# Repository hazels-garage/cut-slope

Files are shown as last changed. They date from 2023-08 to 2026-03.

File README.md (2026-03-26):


<a href="https://discord.gg/jP6hvgNN8r">
  
</a>

# Cut Slope

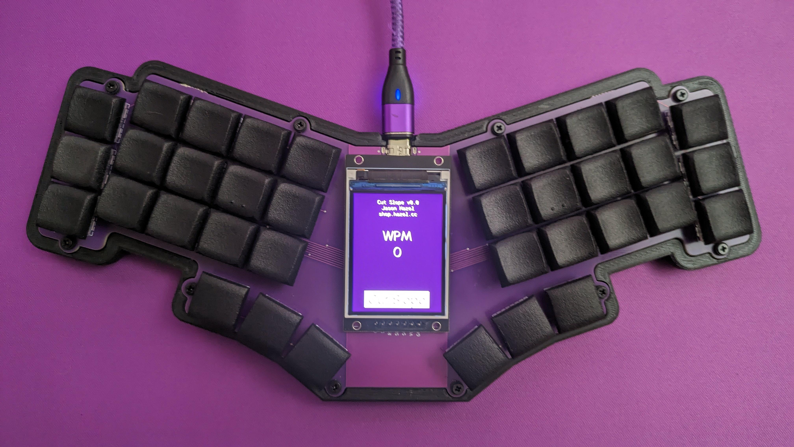
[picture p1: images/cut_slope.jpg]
Cut Slope

_I'm bad at pictures_

## Features
* Integrated RP2040.
* 36 key, choc-spaced, hotswap
* Ortho-ish with dropped/splayed pinkies and fanned thumbs
* Big ass screen support

## Build Guide
* Flash [Firmware](FIRMWARE.md)
* Test matrix with metal tweezers
* Install Hotswap Sockets
* Install Screen
* Done

## Credits
* [Hardware design with RP2040](https://datasheets.raspberrypi.com/rp2040/hardware-design-with-rp2040.pdf)
* [Sleepdealr's RP2040 Design Guide](https://github.com/Sleepdealr/RP2040-designguide)
* [eblastler's ZMK Design Guide](https://github.com/ebastler/zmk-designguide) - Got the SRV05-4 from here
* [Mabroum](https://github.com/AlaaSaadAbdo) - for screen suggestion and moral support
* [Sadek Baroudi](https://github.com/sadekbaroudi) - moral support
* [The Glitch Mob](https://www.youtube.com/watch?v=HD7XAOhkd-w) - for the name

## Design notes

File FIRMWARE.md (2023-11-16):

# Firmware
* [Personal QMK Fork](https://github.com/hazels-garage/qmk_firmware/tree/hazel/cut_slope)
* [ZMK](https://github.com/hazels-garage/zmk-cut-slope) - no wireless or screen
* [VIAL](firmware/hazel_cut_slope_vial.uf2)

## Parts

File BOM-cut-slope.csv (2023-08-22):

Comment | Designator | Footprint | LCSC
B | BOOT1,RESET1 | SW_SPST_TL3342 | C115351
1k | R3,R4 | R_0402_1005Metric | C11702
100nF | C10,C11,C12,C13,C14,C15,C16,C17,C6,C7,C8,C9 | C_0402_1005Metric | C1525
4.7n | C_Shield1 | C_0402_1005Metric | C1538
22pF | C2,C3 | C_0402_1005Metric | C1555
RP2040 | U1 | RP2040-QFN-56 | C2040
USB_C | J1 | Molex-216990_GCT-USB45xx_HRO-TYPE-C-31-M-13x | C223906
27R | R6,R7 | R_0603_1608Metric | C25190
10k | R5 | R_0402_1005Metric | C25744
5.1k | R1,R2 | R_0402_1005Metric | C25905
1M | R_Shield1 | R_0402_1005Metric | C26083
1uF | C1,C4,C5 | C_0402_1005Metric | C52923
XC6206 | U3 | SOT-23 | C5446
500mA | F1 | Fuse_1206_3216Metric | C70076
1N4148W | D1,D10,D11,D12,D13,D14,D15,D16,D17,D18,D19,D2,D20,D21,D22,D23,D24,D25,D26,D27,D28,D29,D3,D30,D31,D32,D33,D34,D35,D36,D4,D5,D6,D7,D8,D9 | D_SOD-123 | C81598
SRV05-4 | U2 | SOT-23-6-routable | C85364
12MHz | Y1 | Crystal_SMD_3225-4Pin_3.2x2.5mm | C9002
W25Q128JVS | U4 | SOIC-8_5.23x5.23mm_P1.27mm | C97521

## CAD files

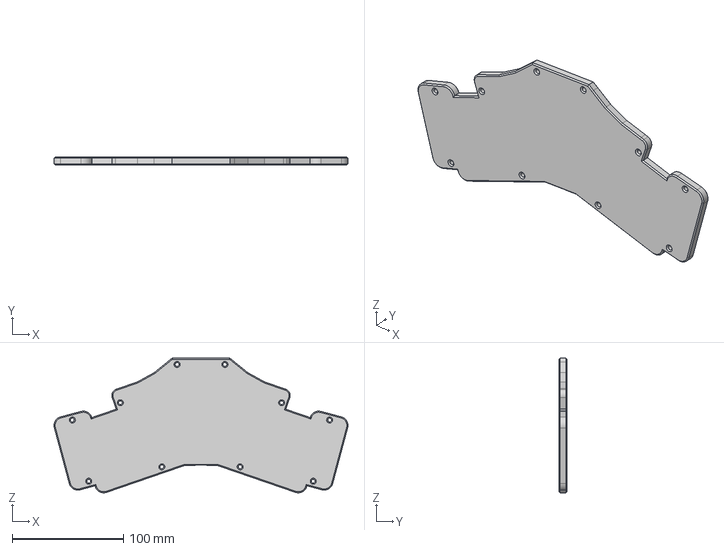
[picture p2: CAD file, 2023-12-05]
case/tray case.step
264.7 x 7.00 x 121.3 mm

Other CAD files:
case/tray case.stl

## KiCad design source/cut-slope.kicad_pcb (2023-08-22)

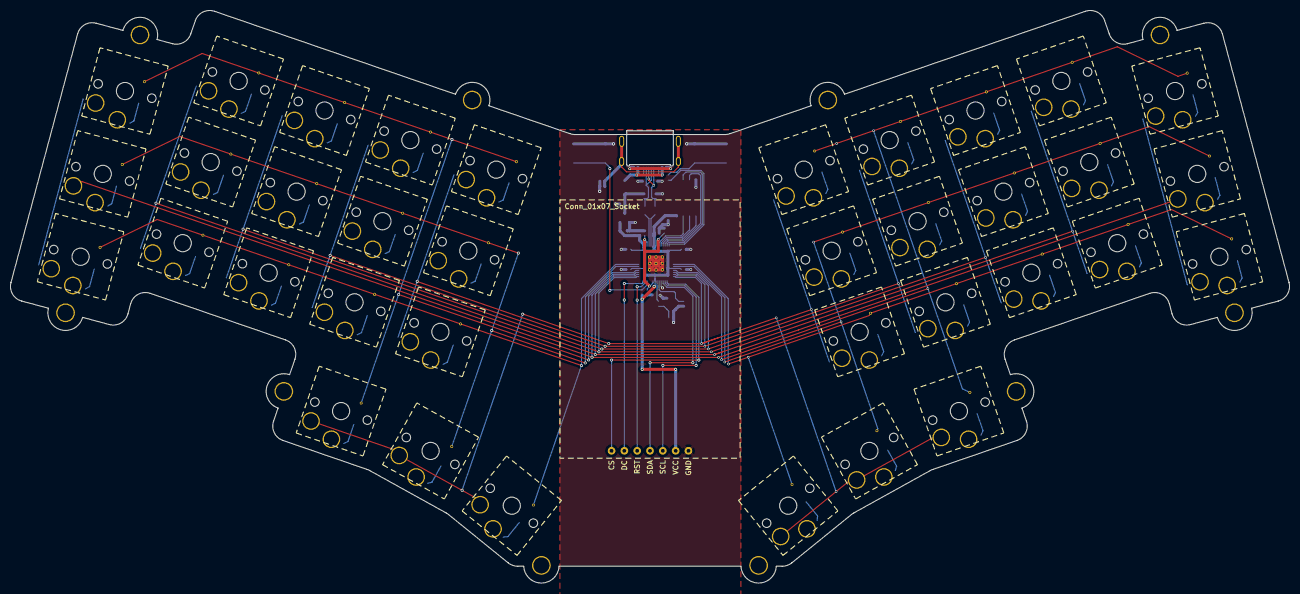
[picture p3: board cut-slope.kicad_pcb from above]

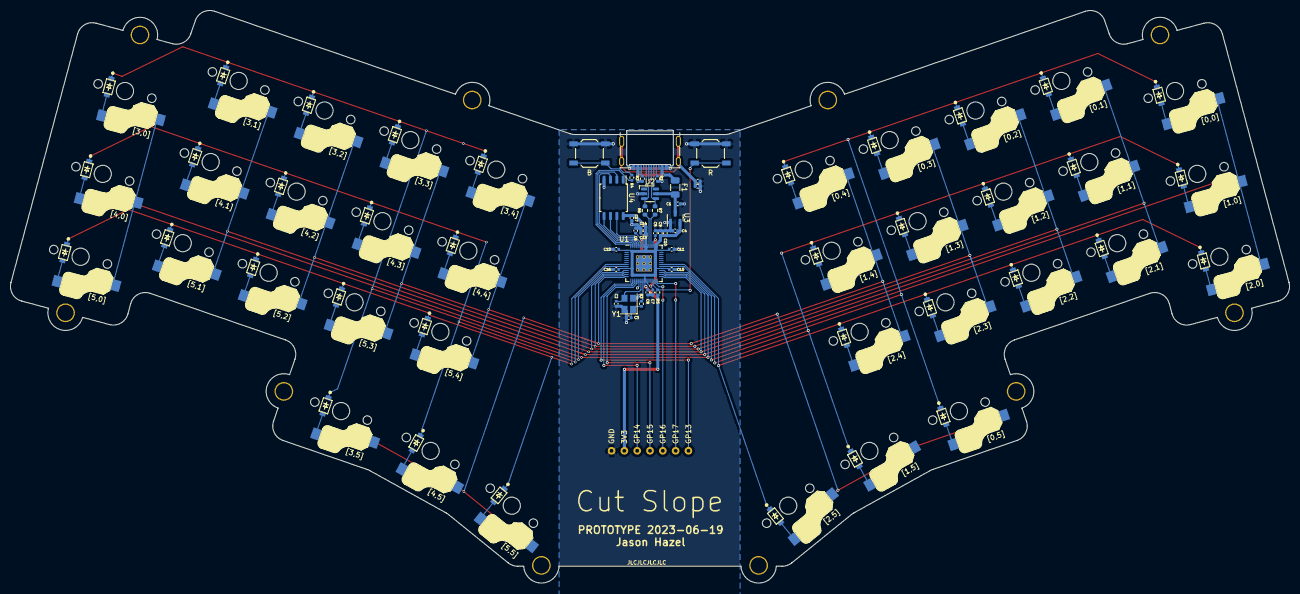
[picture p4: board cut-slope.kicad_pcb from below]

Board: 2 copper layers, 253.5 x 113.5 mm, 119 parts (71 on the bottom side), 76 nets.

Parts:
BOOT1: B; SW_SPST_TL3342
C1, C4, C5: 1uF; C_0402_1005Metric
C2, C3: 22pF; C_0402_1005Metric
C6, C7, C8, C9, C10, C11, C12, C13, C14, C15, C16, C17: 100nF; C_0402_1005Metric
C_Shield1: 4.7n; C_0402_1005Metric
D1, D2, D3, D4, D5, D6, D7, D8, D9, D10, D11, D12, D13, D14, D15, D16, D17, D18, D19, D20, D21, D22, D23, D24, D25, D26, D27, D28, D29, D30, D31, D32, D33, D34, D35, D36: 1N4148W; D_SOD-123
F1: 500mA; Fuse_1206_3216Metric
H1, H2, H3, H4, H5, H6, H7, H8, H9, H10: MountingHole; MountingHole_3.2mm_M3_thinpad
J1: USB_C; Molex-216990_GCT-USB45xx_HRO-TYPE-C-31-M-13x
J2: Conn_01x07_Socket; big ass screen
JLC1: JLCJLCJLCJLC
R1, R2: 5.1k; R_0402_1005Metric
R3, R4: 1k; R_0402_1005Metric
R5: 10k; R_0402_1005Metric
R6, R7: 27R; R_0603_1608Metric
RESET1: R; SW_SPST_TL3342
R_Shield1: 1M; R_0402_1005Metric
SW1: [2,0]; Choc-1u
SW2: [1,0]; Choc-1u
SW3: [0,0]; Choc-1u
SW4: [2,1]; Choc-1u
SW5: [1,1]; Choc-1u
SW6: [0,1]; Choc-1u
SW7: [2,2]; Choc-1u
SW8: [1,2]; Choc-1u
SW9: [0,2]; Choc-1u
SW10: [2,3]; Choc-1u
SW11: [1,3]; Choc-1u
SW12: [0,3]; Choc-1u
SW13: [2,4]; Choc-1u
SW14: [1,4]; Choc-1u
SW15: [0,4]; Choc-1u
SW16: [0,5]; Choc-1u
SW17: [1,5]; Choc-1u
SW18: [2,5]; Choc-1u
SW19: [5,0]; Choc-1u
SW20: [4,0]; Choc-1u
SW21: [3,0]; Choc-1u
SW22: [5,1]; Choc-1u
SW23: [4,1]; Choc-1u
SW24: [3,1]; Choc-1u
SW25: [5,2]; Choc-1u
SW26: [4,2]; Choc-1u
SW27: [3,2]; Choc-1u
SW28: [5,3]; Choc-1u
SW29: [4,3]; Choc-1u
SW30: [3,3]; Choc-1u
SW31: [5,4]; Choc-1u
SW32: [4,4]; Choc-1u
SW33: [3,4]; Choc-1u
SW34: [3,5]; Choc-1u
SW35: [4,5]; Choc-1u
SW36: [5,5]; Choc-1u
U1: RP2040; RP2040-QFN-56
U2: SRV05-4; SOT-23-6-routable
U3: XC6206; SOT-23
U4: W25Q128JVS; SOIC-8_5.23x5.23mm_P1.27mm
Y1: 12MHz; Crystal_SMD_3225-4Pin_3.2x2.5mm

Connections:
+1V1: C5.1, C6.1, C7.1, U1.23 (DVDD), U1.45 (VREG_VOUT), U1.50 (DVDD)
+3V3: C4.2, C8.1, C9.1, C10.1, C11.1, C12.1, C13.1, C14.1, C15.1, C16.1, C17.1, J2.2, R5.1, U1.1 (IOVDD), U1.10 (IOVDD), U1.22 (IOVDD), U1.33 (IOVDD), U1.42 (IOVDD), U1.43 (ADC_AVDD), U1.44 (VREG_VIN), U1.48 (USB_VDD), U1.49 (IOVDD), U3.2 (VO), U4.8 (VCC)
+5V: C1.2, F1.2, U2.5 (VP), U3.3 (VI)
/DC: J2.6, U1.28 (GPIO17)
/RST: J2.5, U1.27 (GPIO16)
/SPI1_CS: J2.7, U1.16 (GPIO13)
/SPI1_MOSI: J2.4, U1.18 (GPIO15)
/SPI1_SCK: J2.3, U1.17 (GPIO14)
/col0: SW1.1, SW2.1, SW3.1, SW19.1, SW20.1, SW21.1, U1.31 (GPIO20)
/col1: SW4.1, SW5.1, SW6.1, SW22.1, SW23.1, SW24.1, U1.30 (GPIO19)
/col2: SW7.1, SW8.1, SW9.1, SW25.1, SW26.1, SW27.1, U1.29 (GPIO18)
/col3: SW10.1, SW11.1, SW12.1, SW28.1, SW29.1, SW30.1, U1.12 (GPIO9)
/col4: SW13.1, SW14.1, SW15.1, SW31.1, SW32.1, SW33.1, U1.13 (GPIO10)
/col5: SW16.1, SW17.1, SW18.1, SW34.1, SW35.1, SW36.1, U1.14 (GPIO11)
/row0: D3.1 (K), D6.1 (K), D9.1 (K), D12.1 (K), D15.1 (K), D16.1 (K), U1.32 (GPIO21)
/row1: D2.1 (K), D5.1 (K), D8.1 (K), D11.1 (K), D14.1 (K), D17.1 (K), U1.34 (GPIO22)
/row2: D1.1 (K), D4.1 (K), D7.1 (K), D10.1 (K), D13.1 (K), D18.1 (K), U1.35 (GPIO23)
/row3: D21.1 (K), D24.1 (K), D27.1 (K), D30.1 (K), D33.1 (K), D34.1 (K), U1.11 (GPIO8)
/row4: D20.1 (K), D23.1 (K), D26.1 (K), D29.1 (K), D32.1 (K), D35.1 (K), U1.9 (GPIO7)
/row5: D19.1 (K), D22.1 (K), D25.1 (K), D28.1 (K), D31.1 (K), D36.1 (K), U1.8 (GPIO6)
/rp2040/CC1: J1.A5 (CC1), R1.1
/rp2040/CC2: J1.B5 (CC2), R2.1
/rp2040/D_+: R6.2, U1.47 (D+)
/rp2040/D_-: R7.2, U1.46 (D-)
/rp2040/XTAL_O: C3.2, R3.1, Y1.1
/rp2040/~USB_BOOT: BOOT1.1, R4.1
CS: R4.2, U1.56 (QSPI_SS_N), U4.1 (~CS)
DBUS+: J1.A6 (D+), J1.B6 (D+), R6.1, U2.3 (IO2)
DBUS-: J1.A7 (D-), J1.B7 (D-), R7.1, U2.4 (IO3)
GND: BOOT1.2, C1.1, C2.1, C3.1, C4.1, C5.2, C6.2, C7.2, C8.2, C9.2, C10.2, C11.2, C12.2, C13.2, C14.2, C15.2, C16.2, C17.2, C_Shield1.1, J1.A1 (GND), J1.A12 (GND), J1.B1 (GND), J1.B12 (GND), J2.1, R1.2, R2.2, RESET1.2, R_Shield1.2, U1.19 (TESTEN), U1.57 (GND), U2.2 (VN), U3.1 (GND), U4.4 (GND), Y1.2, Y1.4
GNDREF: C_Shield1.2, J1.S1 (SHIELD), R_Shield1.1
unnamed: D1.2 (A), SW1.2
unnamed: D2.2 (A), SW2.2
unnamed: D3.2 (A), SW3.2
unnamed: D4.2 (A), SW4.2
unnamed: D5.2 (A), SW5.2
unnamed: D6.2 (A), SW6.2
unnamed: D7.2 (A), SW7.2
unnamed: D8.2 (A), SW8.2
unnamed: D9.2 (A), SW9.2
unnamed: D10.2 (A), SW10.2
unnamed: D11.2 (A), SW11.2
unnamed: D12.2 (A), SW12.2
unnamed: D13.2 (A), SW13.2
unnamed: D14.2 (A), SW14.2
unnamed: D15.2 (A), SW15.2
unnamed: D16.2 (A), SW16.2
unnamed: D17.2 (A), SW17.2
unnamed: D18.2 (A), SW18.2
unnamed: D19.2 (A), SW19.2
unnamed: D20.2 (A), SW20.2
unnamed: D21.2 (A), SW21.2
unnamed: D22.2 (A), SW22.2
unnamed: D23.2 (A), SW23.2
unnamed: D24.2 (A), SW24.2
unnamed: D25.2 (A), SW25.2
unnamed: D26.2 (A), SW26.2
unnamed: D27.2 (A), SW27.2
unnamed: D28.2 (A), SW28.2
unnamed: D29.2 (A), SW29.2
unnamed: D30.2 (A), SW30.2
unnamed: D31.2 (A), SW31.2
unnamed: D32.2 (A), SW32.2
unnamed: D33.2 (A), SW33.2
unnamed: D34.2 (A), SW34.2
unnamed: D35.2 (A), SW35.2
unnamed: D36.2 (A), SW36.2
QSPI_CLK: U1.52 (QSPI_SCLK), U4.6 (CLK)
SD0: U1.53 (QSPI_SD0), U4.5 (DI(IO0))
SD1: U1.55 (QSPI_SD1), U4.2 (DO(IO1))
SD2: U1.54 (QSPI_SD2), U4.3 (IO2)
SD3: U1.51 (QSPI_SD3), U4.7 (IO3)
VBUS: F1.1, J1.A4 (VBUS), J1.A9 (VBUS), J1.B4 (VBUS), J1.B9 (VBUS)
XTAL_IN: C2.2, U1.20 (XTAL_IN), Y1.3
XTAL_OUT: R3.2, U1.21 (XTAL_OUT)
~RESET: R5.2, RESET1.1, U1.26 (~RUN)

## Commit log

2023-07-01 adding tray case
    [tray case.stl]
2023-08-22 some source code maybe?
    [BOM-cut-slope.csv, cut-slope.kicad_pcb, cut-slope.kicad_sch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]
2023-12-05 add step
    [tray case.step]
2023-12-05 how'd my dumbass miss a chamfer on one of the bottom mounting holes?
    [tray case.step, tray case.stl]

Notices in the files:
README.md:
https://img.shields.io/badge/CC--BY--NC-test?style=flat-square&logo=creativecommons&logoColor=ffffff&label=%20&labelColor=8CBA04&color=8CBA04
